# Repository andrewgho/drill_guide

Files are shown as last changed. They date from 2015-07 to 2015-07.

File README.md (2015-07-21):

Drill Guide - ¾″ Dowel Drill Guides
===================================

This repository contains
[OpenSCAD](http://www.openscad.org/)
source files suitable for 3-D printing a jig designed to drill coaxial
pilot holes into the ends of two or more ¾″ hardwood dowel, so they can
be joined together with ¼″ dowel screws; and to drill a pilot hole for
a #8 wood screw, which will affix a window opening hook on one dowel end.

Motivation
----------

My building has very tall living room windows, which have awning windows
very high up, about 12′ high. The windows open outwards, providing nice
airflow in the warm California summer. The locking levers on the window
feature small holes designed to be actuated by a
[transom window hook](http://www.amazon.com/Prime-Line-Products-172655-Transom-Window/dp/B00EO8YI6G)
mounted on a long ¾″ diameter pole.

It turns out to be very difficult to find ¾″ diameter poles in a length
as long as 8–10′. However, it is straightforward to find 4′ long
hardwood dowels, which could then be joined together end to end using
[dowel screws](http://www.mcfeelys.com/screws-fasteners/hanger-bolts-dowel-screws/dowel-screws/1-4-x-1-1-2-dowel-dry-lube-screw-qty-10-8vx40.html).

Drilling straight coaxial holes in the ends of dowels is quite
difficult, and usually requires a drill press and a custom jig. The 3-D
models in this repository are designed to create small plastic or metal
drill guides and support struts so a ¾″ diameter dowel can be clamped
down onto a flat table, and then have straight coaxial and side holes
drilled into it with a hand drill.

Meta
----

* Home: <https://github.com/andrewgho/drill_guide>
* Authors: <https://github.com/andrewgho>

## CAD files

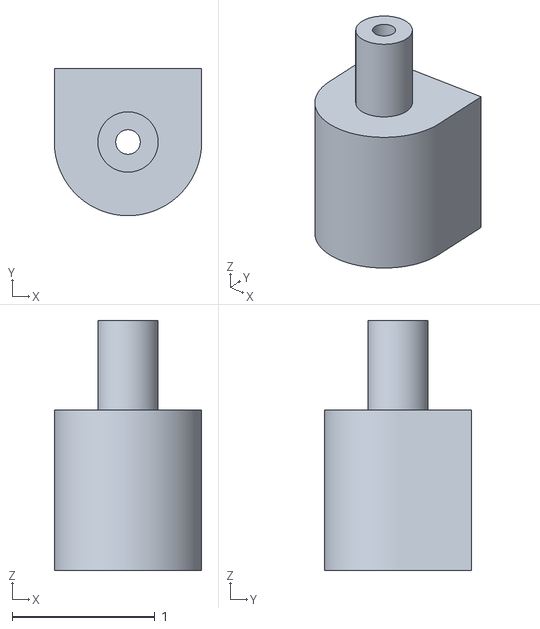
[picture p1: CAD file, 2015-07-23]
drill_guide_coaxial.stl
1.03 x 1.03 x 1.75

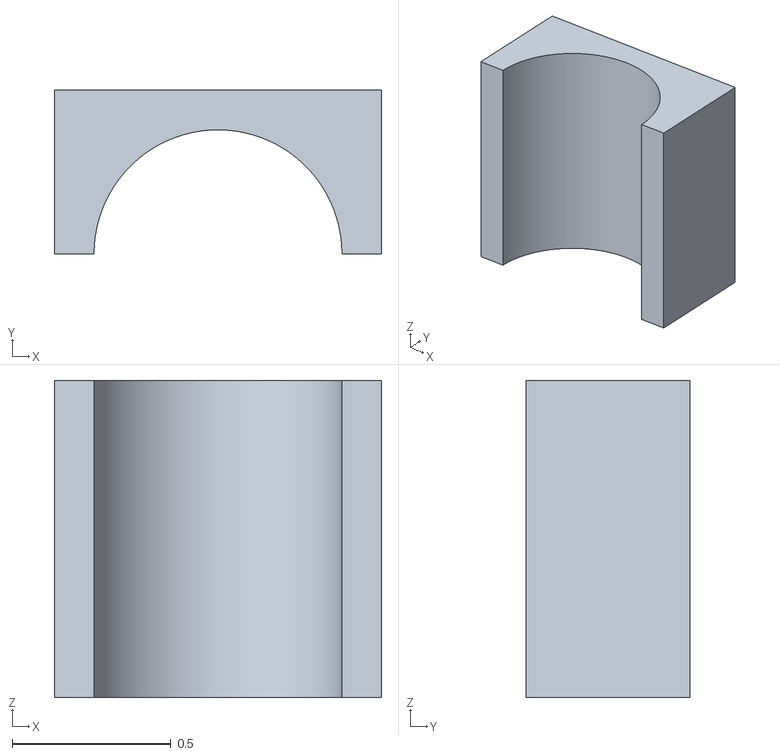
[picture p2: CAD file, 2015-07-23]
support_strut.stl
1.03 x 0.516 x 1.00

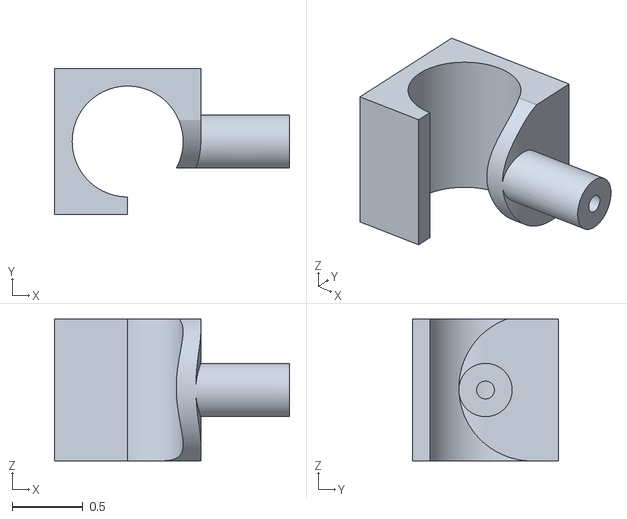
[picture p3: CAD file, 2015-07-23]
drill_guide_side.stl
1.66 x 1.03 x 1.00

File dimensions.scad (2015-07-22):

// dimensions.scad - configurable dimensions for 3/4" dowel drill guides
// Andrew Ho (andrew@zeuscat.com)
//
// This file contains configurable dimensions for a jig designed to
// center and guide an 11/64" drill bit to drill a coaxial hole for a
// 1/4" shank wood screw into the end of a 3/4" hardwood dowel, and a
// 1/8" drill bit to drill a sideways hole for a #8 wood screw into the
// side of the dowel.

guide_height = 3/4;           // Height of drill guides
shaft_height = 1;             // Just how far the dowel enters into the shaft
inner_diameter = 3/4 + 1/32;  // Diameter of dowel, plus fudge factor
hull_thickness = 1/8;         // Size of thinnest wall

// Interpolated values
total_height = guide_height + shaft_height;
double_hull_thickness = hull_thickness * 2;
outer_diameter = inner_diameter + double_hull_thickness;

// Draw cylinder with 1° segments in preview mode
module cylinder360(height, diameter) {
  cylinder(h = height, d = diameter, $fn = 360);
}

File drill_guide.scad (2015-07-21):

// drill_guide.scad - main portion of 3/4" dowel drill guide
// Andrew Ho (andrew@zeuscat.com)
//
// This file contains the main drill guide portion of a jig designed to
// center and guide an 11/16" drill bit to drill a coaxial hole for a
// 1/4" drill bit into the end of a 3/4" hardwood dowel.
//
// Shapeways part link:
// http://www.shapeways.com/product/2CF7BEVJN/3-4-quot-dowel-drill-guide

include <dimensions.scad>;

difference() {
  // Squared off bottom, rounded top, drill guide extension
  union() {
    translate([-outer_diameter / 2, 0, 0])
      cube([outer_diameter, outer_diameter / 2, shaft_height + hull_thickness]);
    cylinder360(shaft_height + hull_thickness, outer_diameter);
    cylinder360(total_height, hole_diameter + double_hull_thickness);
  }

  // Drill through hole, shaft for dowel
  union() {
    cylinder360(total_height, hole_diameter);
    cylinder360(shaft_height, inner_diameter);
  }
}

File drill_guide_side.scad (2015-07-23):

// drill_guide_side.scad - 3/4" dowel side hole drill guide
// Andrew Ho (andrew@zeuscat.com)
//
// Center and guide an 1/8" drill bit to drill a hole for a #8 wood screw
// into the side of a 3/4" hardwood dowel.

include <dimensions.scad>;

// Hole diameter of 1/8" is for #8 wood screw in hardwood:
// http://www.wlfuller.com/html/wood_screw_chart.html
hole_diameter = 1/8;

// Prevent edge rendering artifacts in OpenSCAD preview mode
extra = 1/64;

difference() {
  // Squared off bottom and far side, rounded top, drill guide extension
  union() {
    translate([-outer_diameter / 2, 0, 0])
      cube([outer_diameter, outer_diameter / 2, shaft_height]);
    translate([-outer_diameter / 2, -outer_diameter / 2, 0])
      cube([outer_diameter / 2, outer_diameter, shaft_height]);
    cylinder360(shaft_height, outer_diameter);
    translate([0, 0, shaft_height / 2])
    rotate([0, 90, 0])
      cylinder360((inner_diameter / 2) + guide_height,
                  hole_diameter + double_hull_thickness);
  }

  // Lop off area for easier printing, drill through hole, shaft for dowel
  union() {
    rotate([0, 90, 0])
    translate([-outer_diameter,
               (-outer_diameter / 2) - ((hole_diameter / 2) + hull_thickness),
               0])
      difference() {
        translate([-extra, 0, 0])
          cube([outer_diameter + (2 * extra),
                outer_diameter,
                shaft_height]);
        translate([outer_diameter / 2, outer_diameter, 0])
          cylinder360(shaft_height, outer_diameter);
      }
    translate([-extra, 0, shaft_height / 2])
    rotate([0, 90, 0])
      cylinder360((inner_diameter / 2) + guide_height + (extra * 2),
                  hole_diameter);
    translate([0, 0, -extra])
      cylinder360(shaft_height + (extra * 2), inner_diameter);
  }
}

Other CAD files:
drill_guide_coaxial.scad
support_strut.scad

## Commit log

2015-07-20 Initial repository creation
    [drill_guide.scad]
2015-07-20 Fix Shapeways public link
    [drill_guide.scad]
2015-07-21 Square off bottom end of drill guide, so it can be clamped to a flat surface; add support strut to clamp rest of dowel; factor out shared dimensions; add Makefile for command line generation of STL f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
    [dimensions.scad, drill_guide.scad, support_strut.scad]
2015-07-21 Add side hole drill guide; refactor pilot hole dimensions into individual drill guide files; add Markdown README
    [dimensions.scad, drill_guide_coaxial.scad, drill_guide_side.scad]
2015-07-21 Add STL files
    [drill_guide_coaxial.stl, drill_guide_side.stl, support_strut.stl]
2015-07-22 Add 1/64" fudge factor for dowel shaft
    [dimensions.scad, drill_guide_coaxial.stl, drill_guide_side.stl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]
2015-07-22 Change fudge factor to 1/32"
    [dimensions.scad]
2015-07-22 Square off second edge and lop off some material for easier top-down printing
    [drill_guide_side.scad]
2015-07-22 Regenerate STL files
    [drill_guide_coaxial.stl, drill_guide_side.stl, support_strut.stl]
2015-07-23 Add extra fudge factor for subtractive elements, to prevent edge rendering artifacts in OpenSCAD preview mode
    [drill_guide_coaxial.scad, drill_guide_coaxial.stl, drill_guide_side.scad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]
